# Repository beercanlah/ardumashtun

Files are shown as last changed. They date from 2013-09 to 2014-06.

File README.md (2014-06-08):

Ardumashtun
===========

Ardumashtun, an Arduino controlled recirculating mashtun. 

Do you want to improve your home brewing? This projects contains all you need to turn a water heater into a recirculating mash tun. You can find
[more info about our recirculating mash tun](http://beercanlah.com/?page_id=49)
on the blog [beercanlah.com](http://beercanlah.com/).
Here we develop the hard and software that we use to improve our nano brewery.

This repositories contains software for the Arduino. We also provide the eagle cad design design files for the hardware.

Software
------------

We have two different versions of the Arduino sketch that runs our software. One intended for use with an Arduino Uno, and one for use with an Arduino Yun.
When using the Uno you control your mashtun via USB, while the Yun enables you to control your mashtun via the browser.

You can also take a look at the app used for controlling the Uno based mash tun, [kivybrew](https://github.com/beercanlah/kivybrew), and the one controlling the Yun based mash tun, [flapibrew](https://github.com/beercanlah/flapibrew).

Hardware
-------------
Version one of the Ardumashtun hardware is a custom Arduino shield intended to be fabricated by a PCB mill. Recently we have started to migrate towards [Seeedstudios](http://www.seeedstudio.com/) PCB and PCBA service.  We have a running prototype board that only uses parts from the Open Parts Library, so that it can be manufactured using Seeedstudios Fusion PCBA.

License
----------

Unless specifically stated otherwise, everything is licensed under the MIT license, for more information see
LICENSE.txt.

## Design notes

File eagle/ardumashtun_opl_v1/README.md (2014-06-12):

Overview
--------

ardumashtun_opl_v1 is the first attempt to build the mash tun controller using the PCBA service by seeedstudio. 
It works, there are however improvements which we might make in a future version.

Possible Improvements
---------------------

* Label pin header on silk screen
* Add voltage divider on digital pin 0 for use as 3.3 V serial

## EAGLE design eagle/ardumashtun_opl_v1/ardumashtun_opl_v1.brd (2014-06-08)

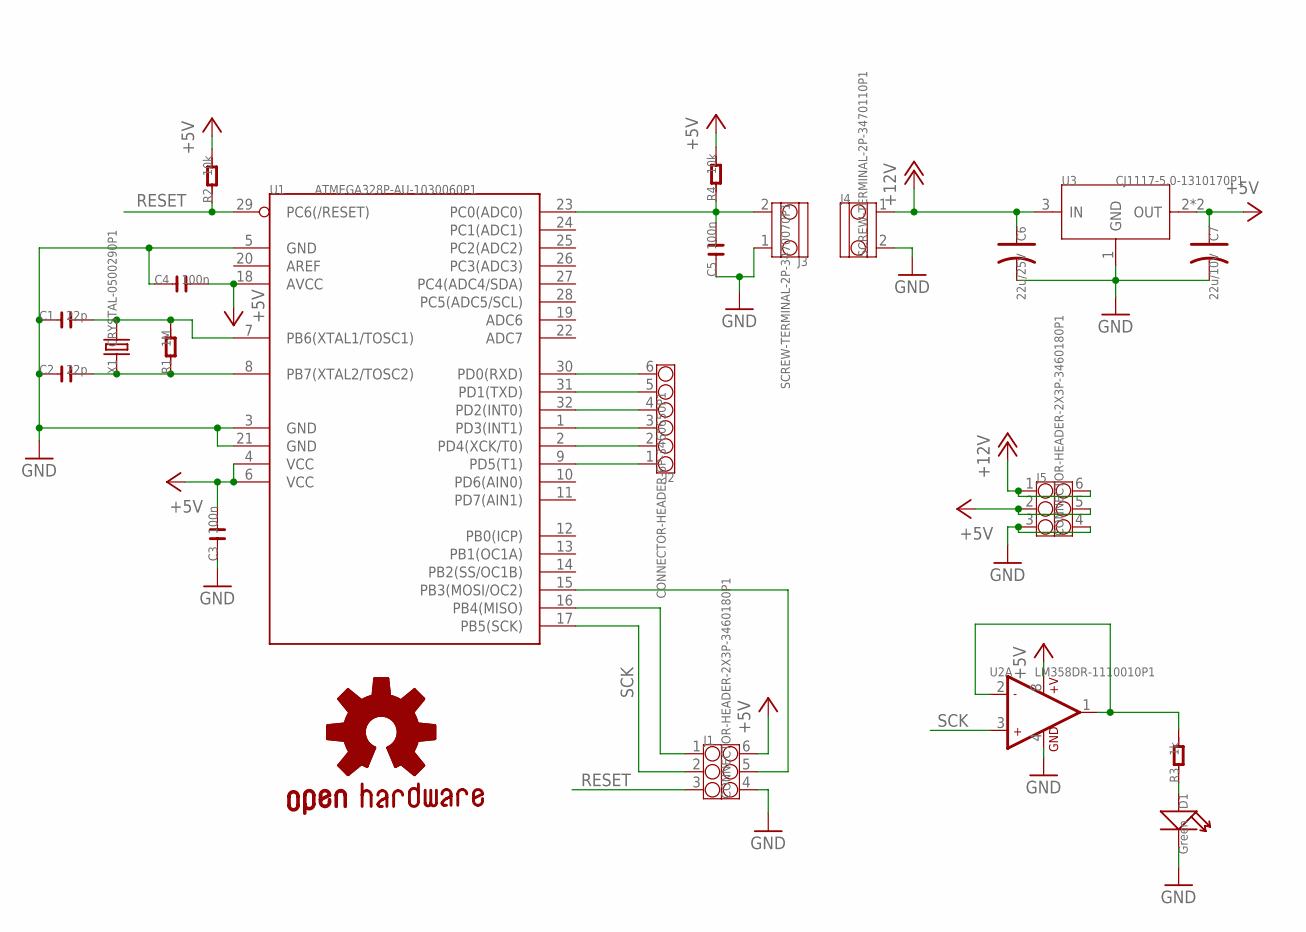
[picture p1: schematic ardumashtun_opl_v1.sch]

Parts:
C1, C2: 22p; C0603
C3, C4, C5: 100n; C0603
C6: 22u/25V; AVX-C
C7: 22u/10V; AVX-B
D1: Green; LED0603
GOLD_ORB_SM1: OSHWLOGO_GOLD_ORB_SM; OSHW2
J1, J5: CONNECTOR-HEADER-2X3P-3460180P1; 2X3P-2.54-2.54-11.6-3.0-BLACK-MALE
J2: CONNECTOR-HEADER-6P-3460650P1; 1X6P-2.54-2.54-11.6-3.0-BLACK-MALE
J3: SCREW-TERMINAL-2P-3470070P1; 2P-3.5
J4: SCREW-TERMINAL-2P-3470110P1; 2P-5.0
R1: 1M; R0603
R2, R4: 10k; R0603
R3: 1k; R0603
U1: ATMEGA328P-AU-1030060P1; TQFP32
U2: LM358DR-1110010P1; SOIC8
U3: CJ1117-5.0-1310170P1; SOT223
X1: CRYSTAL-0500290P1; 2P-SMD-5.0X3.2

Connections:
+5V: C3.2, C4.2, C7.+ (1), J1.6, J5.2, J5.5, R2.2, R4.2, U1.4 (VCC), U1.6 (VCC), U1.18 (AVCC), U2.8 (+V), U3.2 (OUT), U3.TER (OUT)
+12V: C6.+ (1), J4.1, J5.1, J5.6, U3.3 (IN)
GND: C1.1, C2.1, C3.1, C4.1, C5.1, C6.- (2), C7.- (2), D1.-, J1.4, J3.1, J4.2, J5.3, J5.4, U1.3 (GND), U1.5 (GND), U1.21 (GND), U2.4 (GND), U3.1 (GND)
unnamed: C1.2, R1.2, U1.7 (PB6(XTAL1/TOSC1)), X1.2
unnamed: C2.2, R1.1, U1.8 (PB7(XTAL2/TOSC2)), X1.1
unnamed: R3.2, U2.1 (OUT1), U2.2 (-IN1)
unnamed: J1.1, U1.16 (PB4(MISO))
unnamed: J1.5, U1.15 (PB3(MOSI/OC2))
unnamed: D1.+, R3.1
unnamed: J2.6, U1.30 (PD0(RXD))
unnamed: J2.5, U1.31 (PD1(TXD))
unnamed: J2.4, U1.32 (PD2(INT0))
unnamed: J2.3, U1.1 (PD3(INT1))
unnamed: J2.2, U1.2 (PD4(XCK/T0))
unnamed: J2.1, U1.9 (PD5(T1))
unnamed: C5.2, J3.2, R4.1, U1.23 (PC0(ADC0))
RESET: J1.3, R2.1, U1.29 (PC6(/RESET))
SCK: J1.2, U1.17 (PB5(SCK)), U2.3 (+IN1)

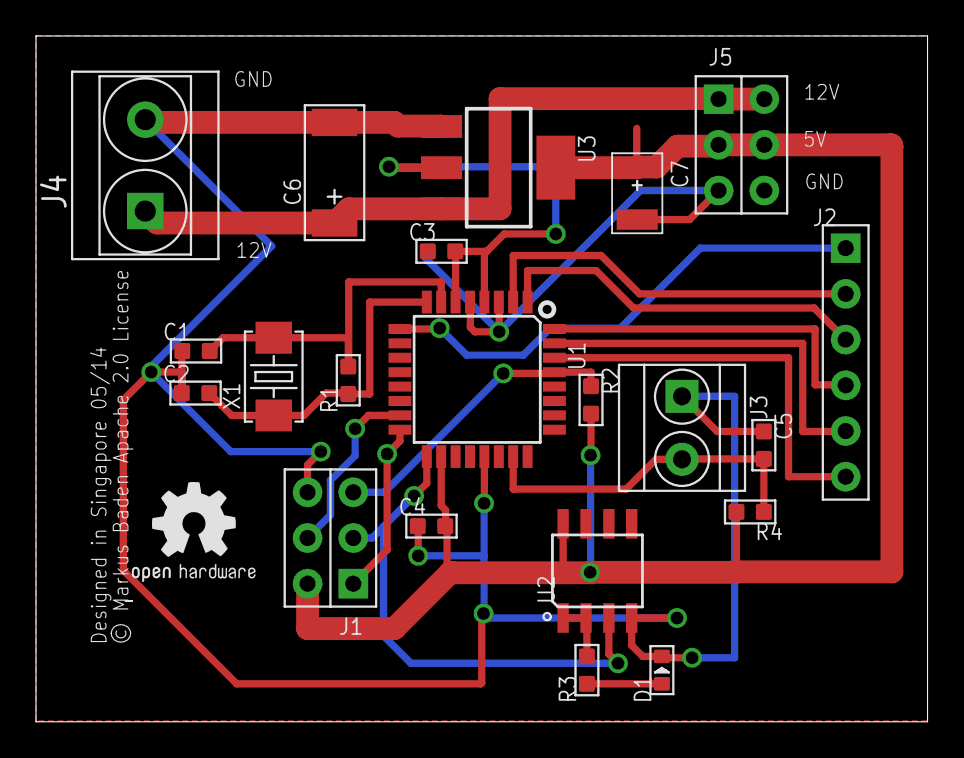
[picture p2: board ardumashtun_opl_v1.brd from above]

Board: 2 copper layers, 49.5 x 38.1 mm, 22 parts (0 on the bottom side), 18 nets.

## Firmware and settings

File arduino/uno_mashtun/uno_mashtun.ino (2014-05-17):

// Uses CmdMessenger version 3.6
// get it from https://github.com/thijse/Arduino-Libraries
#include <CmdMessenger.h>

// Get it from https://github.com/br3ttb/Arduino-PID-Library
#include <PID_v1.h>

const byte pumpPin = 2;
const byte heaterPin = 4;

unsigned long currentMillis;
unsigned long previousMillis;
byte slowCount;


// Lookup table for thermistor. Substract adcSubstract from ADC and then
// use the result as an index. Temp is in 23.1 format. Range from -5
// to 40 degrees only. Calculated for bridge formed by therm, 15k and 4.7V
// the therm is 10k at 25C and has a B of 3988
double temperature;
double setpoint;
double dutyCycle;
double pValue = 10;
double iValue = 0.11;
PID temperaturePID(&temperature, &dutyCycle, &setpoint, pValue, iValue, 0, DIRECT);
  
const int adcSubstract = 51;
const int adcMax = 784;
const int temperatureTable[] PROGMEM = {1093,1086,1078,1071,1064,1057,1051,1044,1037,1031,1025,1019,1013,1007,1001,995,990,984,979,974,968,963,958,953,948,943,939,934,929,925,920,916,911,907,903,898,894,890,886,882,878,874,870,867,863,859,855,852,848,844,841,837,834,831,827,824,820,817,814,811,808,804,801,798,795,792,789,786,783,780,777,774,772,769,766,763,760,758,755,752,750,747,744,742,739,736,734,731,729,726,724,721,719,717,714,712,709,707,705,702,700,698,696,693,691,689,687,684,682,680,678,676,674,672,669,667,665,663,661,659,657,655,653,651,649,647,645,643,641,639,637,636,634,632,630,628,626,624,623,621,619,617,615,614,612,610,608,606,605,603,601,600,598,596,594,593,591,589,588,586,584,583,581,579,578,576,575,573,571,570,568,567,565,564,562,560,559,557,556,554,553,551,550,548,547,545,544,542,541,539,538,537,535,534,532,531,529,528,527,525,524,522,521,520,518,517,515,514,513,511,510,509,507,506,505,503,502,501,499,498,497,495,494,493,491,490,489,488,486,485,484,482,481,480,479,477,476,475,474,472,471,470,469,468,466,465,464,463,461,460,459,458,457,455,454,453,452,451,450,448,447,446,445,444,443,441,440,439,438,437,436,434,433,432,431,430,429,428,427,425,424,423,422,421,420,419,418,417,415,414,413,412,411,410,409,408,407,406,405,404,403,401,400,399,398,397,396,395,394,393,392,391,390,389,388,387,386,385,384,383,382,381,380,379,377,376,375,374,373,372,371,370,369,368,367,366,365,364,363,362,361,360,359,358,357,356,355,354,354,353,352,351,350,349,348,347,346,345,344,343,342,341,340,339,338,337,336,335,334,333,332,331,330,329,329,328,327,326,325,324,323,322,321,320,319,318,317,316,315,314,314,313,312,311,310,309,308,307,306,305,304,303,303,302,301,300,299,298,297,296,295,294,293,293,292,291,290,289,288,287,286,285,284,284,283,282,281,280,279,278,277,276,275,275,274,273,272,271,270,269,268,268,267,266,265,264,263,262,261,260,260,259,258,257,256,255,254,253,253,252,251,250,249,248,247,247,246,245,244,243,242,241,240,240,239,238,237,236,235,234,234,233,232,231,230,229,228,228,227,226,225,224,223,222,222,221,220,219,218,217,216,216,215,214,213,212,211,210,210,209,208,207,206,205,204,204,203,202,201,200,199,198,198,197,196,195,194,193,192,192,191,190,189,188,187,186,186,185,184,183,182,181,181,180,179,178,177,176,175,175,174,173,172,171,170,169,169,168,167,166,165,164,163,163,162,161,160,159,158,157,157,156,155,154,153,152,151,151,150,149,148,147,146,145,145,144,143,142,141,140,139,139,138,137,136,135,134,133,133,132,131,130,129,128,127,126,126,125,124,123,122,121,120,120,119,118,117,116,115,114,113,113,112,111,110,109,108,107,106,105,105,104,103,102,101,100,99,98,97,97,96,95,94,93,92,91,90,89,89,88,87,86,85,84,83,82,81,80,80,79,78,77,76,75,74,73,72,71,70,69,69,68,67,66,65,64,63,62,61,60,59,58,57,56,56,55,54,53,52,51,50,49,48,47,46,45,44,43,42,41,40,39,38,37,36,35,34,34,33,32,31,30,29,28,27,26,25,24,23,22,21,20,19,18,17,16,15,14,13,12,11,10,9,8};

unsigned long windowStartTime;
boolean inDutyCycleMode;
boolean heaterIsOn = LOW;
boolean pumpIsOn = LOW;


// Attach CmdMessenger
CmdMessenger cmdMessenger = CmdMessenger(Serial);

// Commands we send from the Arduino to be received on the PC
enum
{
  kAcknowledge,
  kError,
  kFullStatus,
  kTemperature,
  kPumpStatus,
  kHeaterStatus,
  kDutyCycleStatus,
  kPIDStatus,
  kSetpointStatus,
  kPValueStatus,
  kIValueStatus,
  kPID,
  kDutyCycle,
  kPump,
  kSetpoint,
  kPValue,
  kIValue,
};

void onTemperature() {
  cmdMessenger.sendCmd(kTemperature, temperature);
}

void onPumpStatus() {
  cmdMessenger.sendCmd(kPumpStatus, pumpIsOn);
}

void onHeaterStatus() {
  cmdMessenger.sendCmd(kHeaterStatus, heaterIsOn);
}

void onDutyCycleStatus() {
  cmdMessenger.sendCmd(kDutyCycleStatus, dutyCycle);
}

void onPIDStatus() {
  cmdMessenger.sendCmd(kPIDStatus, temperaturePID.GetMode());
}

void onSetpointStatus() {
  cmdMessenger.sendCmd(kSetpointStatus, setpoint);
}

void onPValueStatus() {
  cmdMessenger.sendCmd(kSetpointStatus, temperaturePID.GetKp());
}

void onIValueStatus() {
  cmdMessenger.sendCmd(kSetpointStatus, temperaturePID.GetKi());
}

void onPID() {
  bool requestedMode = cmdMessenger.readBoolArg();

  if (requestedMode) {
    temperaturePID.SetMode(AUTOMATIC);
  }
  else {
    temperaturePID.SetMode(MANUAL);
  }
}

void onDutyCycle() {
  float requestedDC = cmdMessenger.readFloatArg();
  setDutyCycle(requestedDC);
}

void onPump() {
  bool requestedStatus = cmdMessenger.readBoolArg();

  if (requestedStatus) {
    pumpOn();
  }
  else {
    pumpOff();
  }
}

void onSetpoint() {
  float reqSetpoint = cmdMessenger.readFloatArg();
  setSetPoint(reqSetpoint);
}

void onPValue() {
  float reqPValue = cmdMessenger.readFloatArg();
  temperaturePID.SetTunings(reqPValue, temperaturePID.GetKi(), 0);
}

void onIValue() {
  float reqIValue = cmdMessenger.readFloatArg();
  temperaturePID.SetTunings(temperaturePID.GetKp(), reqIValue, 0);
}
  

void attachCommandCallbacks() {
  cmdMessenger.attach(kTemperature, onTemperature);
  cmdMessenger.attach(kPumpStatus, onPumpStatus);
  cmdMessenger.attach(kHeaterStatus, onHeaterStatus);
  cmdMessenger.attach(kPIDStatus, onPIDStatus);
  cmdMessenger.attach(kSetpointStatus, onSetpointStatus);
  cmdMessenger.attach(kPValueStatus, onPValueStatus);
  cmdMessenger.attach(kIValueStatus, onIValueStatus);
  cmdMessenger.attach(kPID, onPID);
  cmdMessenger.attach(kDutyCycleStatus, onDutyCycleStatus);
  cmdMessenger.attach(kDutyCycle, onDutyCycle);
  cmdMessenger.attach(kPump, onPump);
  cmdMessenger.attach(kSetpoint, onSetpoint);
  cmdMessenger.attach(kPValue, onPValue);
  cmdMessenger.attach(kIValue, onIValue);
}

void measureTemperature() {
  int index = analogRead(A0) - adcSubstract;
  if (index < 0)
  {
    index = 0;
  }
  if (index>adcMax)
  {
    index = adcMax;
  }
  int lookup = pgm_read_word(&temperatureTable[index]);
  temperature = double(lookup)/10.0;
}

int temperatureToInt(double temperature) {
  return int(round(10*temperature));
}

void setSetPoint(double value) {
  setpoint = value;
}
    
void setDutyCycle(double value) {
  // Check bounds
  if (value > 100) {
    value = 100;
  }
  if (value < 0) {
    value = 0;
  }
  dutyCycle = value;
}

void setPValue(double value) {
  pValue = value;
  temperaturePID.SetTunings(pValue, iValue, 0);
}

void setIValue(double value) {
  iValue = value;
  temperaturePID.SetTunings(pValue, iValue, 0);
}
    
void heaterOn() {
  if (!heaterIsOn) {
    digitalWrite(heaterPin, HIGH);
  }
  heaterIsOn = HIGH;
}

void heaterOff() {
  if (heaterIsOn) {
    digitalWrite(heaterPin, LOW);
  }
  heaterIsOn = LOW;
}

void pumpOn() {
  if (!pumpIsOn) {
    digitalWrite(pumpPin, HIGH);
  }
  pumpIsOn = HIGH;
}

void pumpOff() {
  if (pumpIsOn) {
    digitalWrite(pumpPin, LOW);
  }
  pumpIsOn = LOW;
}


// 30 sec
const unsigned long windowSize = 10000;

void controlHeater() {
  // Convert double duty cycle to long for calculation
  unsigned long intDutyCycle = int(dutyCycle);
  
  // If we are not in PID controlled mode
  // we can skip the calculation of the window size
  // and be constantly on or off if the duty cycle is
  // larger then 100 or smaller then 0
  // If we wouldn't check for being in PID mode
  // then the PID would set the duty cycle to 
  // zero, we would exit the dutycycle mode and
  // when the PID sets it greater then zero again enter
  // it again, but the window would be reset... this leads
  // to a lot of relay action around setpoint...
  boolean inPIDmode = temperaturePID.GetMode();
  
  if (!inPIDmode && intDutyCycle < 0) {
    heaterOff();
    inDutyCycleMode = LOW;
  }
  else if (!inPIDmode && intDutyCycle > 99) {
    heaterOn();
    inDutyCycleMode = LOW;
  }
  else {
    // If you just entered duty cycle mode
    // start first window
    if (!inDutyCycleMode) {
      windowStartTime = currentMillis;
    }
    
    // The onTime is windowSize * dutyCycle and since
    // dutyCycle is in percent we divide by 100
    unsigned long onTime = intDutyCycle * (windowSize / 100);
    
    // Shift window time if  needed
    if (currentMillis - windowStartTime > windowSize)
      windowStartTime += windowSize;

    if (currentMillis - windowStartTime < onTime) {
      heaterOn();
    }
    else {
      heaterOff();
    }
    inDutyCycleMode = HIGH;
  }
}

void setup() {
  pinMode(pumpPin, OUTPUT);
  pinMode(heaterPin, OUTPUT);
  dutyCycle = 0;
  
  measureTemperature();
  setpoint = temperature + 1;
  
  temperaturePID.SetMode(MANUAL);
  temperaturePID.SetOutputLimits(0, 100);
  temperaturePID.SetSampleTime(windowSize);
  
  Serial.begin(115200);

  cmdMessenger.printLfCr();
  
  attachCommandCallbacks();
  
  cmdMessenger.sendCmd(kAcknowledge, "Arduino ready");
}

void loop () {
  currentMillis = millis();
  cmdMessenger.feedinSerialData();
  
  if (currentMillis - previousMillis > 100) {
    measureTemperature();
    temperaturePID.Compute();
    controlHeater();
    previousMillis = currentMillis;
    slowCount++;
    if (slowCount > 50) {
      slowCount = 0;
    }
  }
}

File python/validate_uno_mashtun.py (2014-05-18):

import ardumashtun as at
from time import sleep
reload(at)

sleep_time = 0.25

if __name__ == '__main__':
    tun = at.UnoMashtun('/dev/tty.usbmodem1411')

    print 'Testing temperature'
    print tun.temperature

    print 'Turning on pump'
    tun.pump = 1
    sleep(sleep_time)

    print 'Testing pumpStatus'
    print tun.pump

    print 'Turning off pump'
    tun.pump = 0
    sleep(sleep_time)

    print 'Testing pumpStatus again'
    print tun.pump

    print 'Setting duty cycle to 100'
    tun.dutycycle = 100
    sleep(sleep_time)

    print 'Testing duty cycle'
    print tun.dutycycle
    sleep(sleep_time)

    print 'Testing heater'
    print tun.heater

    print 'Setting duty cycle to 0'
    tun.dutycycle = 0
    sleep(sleep_time)

    print 'Testing duty cycle again'
    print tun.dutycycle

    print 'Testing heater again'
    print tun.heater

    print 'Turning pid off'
    tun.pid = 0
    sleep(sleep_time)

    print 'Testing pid'
    print tun.pid

    print 'Turning pid on'
    tun.pid = 1
    sleep(sleep_time)

    print 'Testing pid again'
    print tun.pid

    print 'Setting setpoint to 25.0'
    tun.setpoint = 25.0
    sleep(sleep_time)

    print 'Testing setpoint'
    print tun.setpoint

    print 'Setting pValue to 10.01'
    tun.p_value = 10.01
    sleep(sleep_time)

    print 'Testing pValue'
    print tun.p_value

    print 'Setting iValue to 0.15'
    tun.i_value = 0.15
    sleep(sleep_time)

    print 'Testing iValue'
    print tun.i_value

    tun.serial.close()

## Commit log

2012-01-14 First sketch of zeromq wrapper for serial, that will handle talking to the Arduino
2012-01-22 Pump turns on and off via serial
    Finally got some sort of communications going!
2012-01-23 First script of monitoring temperature committed
2012-01-23 Script to monitor temperature now works
2012-01-23 Brew kettle class now controls pump as well
    Monitor temperature script will be used for PID tuning
2012-01-23 Monitor temperature script as used for heating measurement
2012-01-23 Implemented dutycycle heating
2012-01-23 Further work on duty cycle mode, rewrote brewkettle to parse commands a bit more intelligently. Experimenting with dutycycle mode
    [2012-01-23 1517-p20-5min.csv]
2012-01-24 Changed temperature and dutyCycle to be double so that they are compatible with the PID library
2012-01-24 Seems I run out of sram. Commented a lot of log messages. Now can set PID on of
2012-01-24 Added set pid on off to brewekettle.py
2012-01-24 fixed pid on off message cmd id
2012-01-24 Mistake in changing set pid on off cmd id, were correct
2012-01-26 Played with PID parameters, as used for brew
2012-01-26 arduino sketch as for brew
2012-01-26 monitor temperature as for brew
2012-01-26 Setpoint and temperature now default to NaN
2012-01-26 Timer now based on pyface. No more wx, all traitsui based.
2012-01-26 Dummy serial no puts out temperature for testing the app
2012-01-26 Plot of temperature works, after fixing bug in EPD 7.2, see
    https://github.com/enthought/chaco/commit/
    2cb4fd235b928d737b3c244942f8e2e85aa4270d
    and
    https://mail.enthought.com/pipermail/enthought-dev/2012-January/030489.html
2012-01-27 Added PID mode flag to get all
2012-01-27 Refactored turning pump on and pump off into seperate function
2012-01-27 Added pump is on flag to get all message
2012-01-27 Added dutycycle and temperature to send to UI
2012-01-27 Added buttons to send updates in setpoint and dutycycle
2012-01-27 Added buttons to turn PID and pump on and off
2012-01-28 BUG: Pump off checked for wrong condition
2012-01-28 BUG: Added dutycycle to grab current values
2012-01-29 Added data of last brew
    [2012-01-24 1832.csv, 2012-01-24 1833.csv, 2012-01-24 1900.csv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]
2012-01-29 Added good test data
    [2012-01-24 1631.csv, 2012-01-24 1655.csv]
2013-01-23 Added functionality that one can select the com port and then start communication with the device
2013-02-02 Changed label on comm button
2013-09-14 Cleanup: Removed data dir
    [2012-01-23 1517-p20-5min.csv, 2012-01-24 1631.csv, 2012-01-24 1655.csv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]
2013-09-14 Cleanup: Removed temperature monitor script
2013-09-14 Added eagle schematics and board
    [three_relay_display_v1.brd, three_relay_display_v1.sch]
2013-09-14 Renamed eagle files
    [ardumashtun_v1.brd, ardumashtun_v1.sch]
2014-05-17 Arduino communicates via CmdMessenger 3.5
2014-05-17 Arduino responds to temperature request
2014-05-17 Python class now reads in temperature
2014-05-17 Uno now communicates pump status
2014-05-17 Uno now turns pump on and off
2014-05-17 Uno now communicates heater status
2014-05-17 Message numbers no longer hard coded
    [ardumashtun.py]
2014-05-17 Uno reports pid status
2014-05-17 Removed kHeater as heater is not settable
2014-05-18 Started unittests
    Renamed test script to validate to make sure it won't be discovered as
    as a test.
    [test_ardumashtun.py, validate_uno_mastun.py]
2014-05-18 First test failes successfully
    [test_ardumashtun.py]
2014-05-18 Added pump test
2014-05-18 Removed printing of messages now that there are some tests
2014-05-18 Unit test for reading temperature works
2014-05-18 Temperature read correctly from Uno
    [validate_uno_mashtun.py]
2014-05-18 Unittest for pump passes
2014-05-18 Added one more pump test
2014-05-18 Pump is validated on Uno
2014-05-18 Validated heater, unit test dutycycle
2014-06-08 Moved board v1 to separate folder
    [ardumashtun_v1.brd, ardumashtun_v1.sch]
2014-06-08 Test board using the Open Parts Library added
    The board uses only parts from Seeedstudio's open parts library and
    can be manufactured by the Fusion PCBA service.
    [ardumashtun_opl_v1.GBL, ardumashtun_opl_v1.GBO, ardumashtun_opl_v1.GBP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]

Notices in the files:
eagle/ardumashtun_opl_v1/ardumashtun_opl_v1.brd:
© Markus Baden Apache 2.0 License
